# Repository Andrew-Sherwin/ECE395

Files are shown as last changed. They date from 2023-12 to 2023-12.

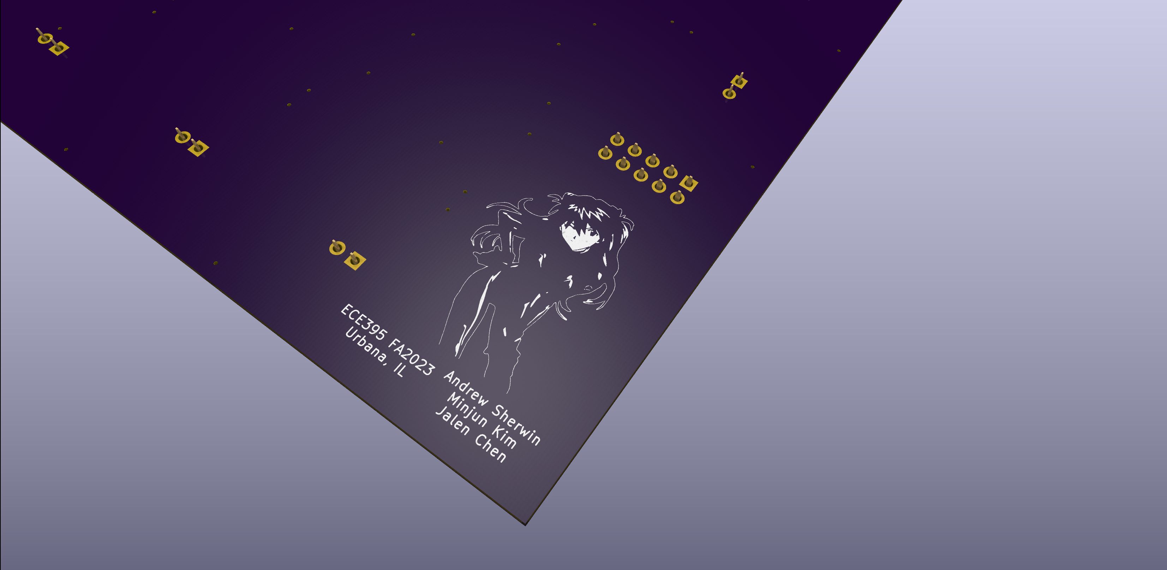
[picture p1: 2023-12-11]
Digital Target System/PCB Art/Asuka Langley/Screen Shot 2023-11-08 at 3.00.52 AM.png

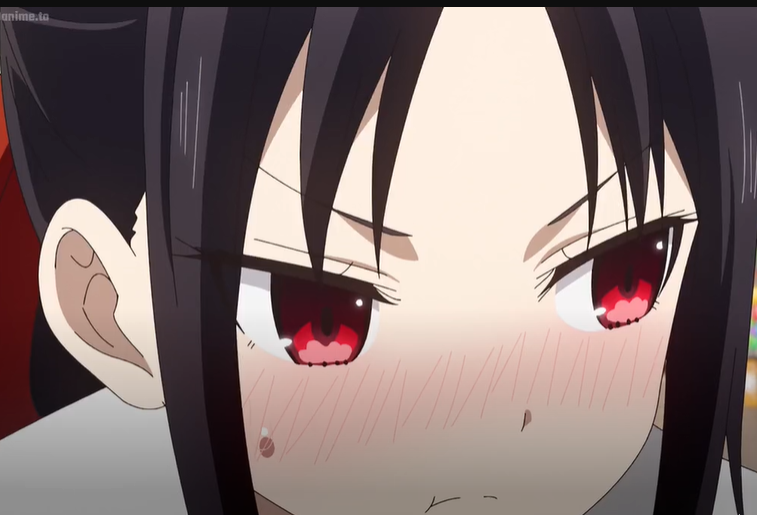
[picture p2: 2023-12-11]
Digital Target System/PCB Art/jalen.png

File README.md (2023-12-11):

# ECE395
Advanced Digital Projects Laboratory
Project: Digital Target System

The Digital Target System folder contains 6 files:
1. Digital Target System Report.pdf
	- This contains the report documenting the design of the product. 
2. DigitalTargetSystem Code (folder)
	- This contains the C code necessary to program the product (if reprogramming or a new revision is needed). 
3. PCB Art (folder)
	- This contains some ART for the silkscreens.
4. PCB with Art (folder)
	- This contains Rev10 PCB KiCad files with Art (unorganized). 
5. Rev8 KiCad Files (folder)
	- This contains Rev8 PCB. A version of the PCB without switches. Power is from the barrel-jack ONLY. 
6. Rev10 KiCad Files (folder)
	- This contains Rev10 PCB. A versino of the PCB wit switches. Power can be from barrel-jack or alternate power source such as a DC Power Supply. 

Updated: December 10, 2023 19:24 CST - Andrew Sherwin

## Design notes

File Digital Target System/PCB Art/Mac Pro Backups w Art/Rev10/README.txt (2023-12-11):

11/06/2023 22:11

- Added switches to toggle which power source to use.

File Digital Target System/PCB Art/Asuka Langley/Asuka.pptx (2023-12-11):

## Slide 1

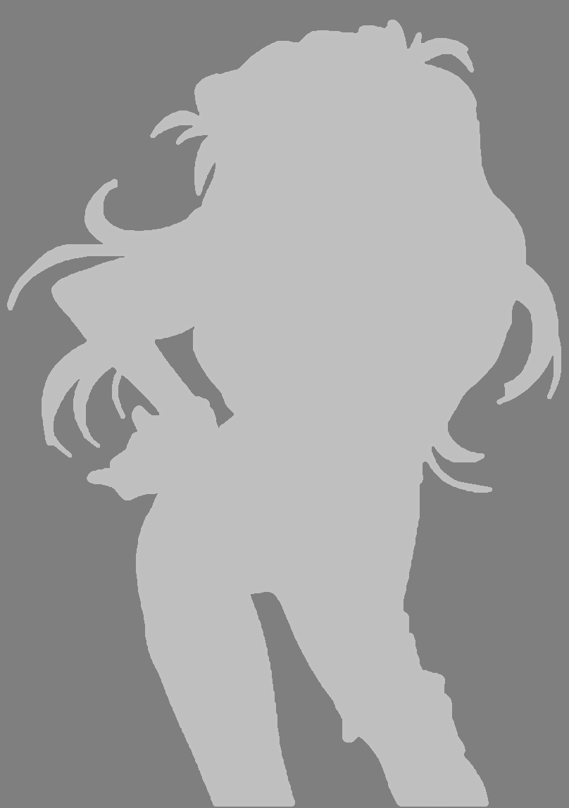
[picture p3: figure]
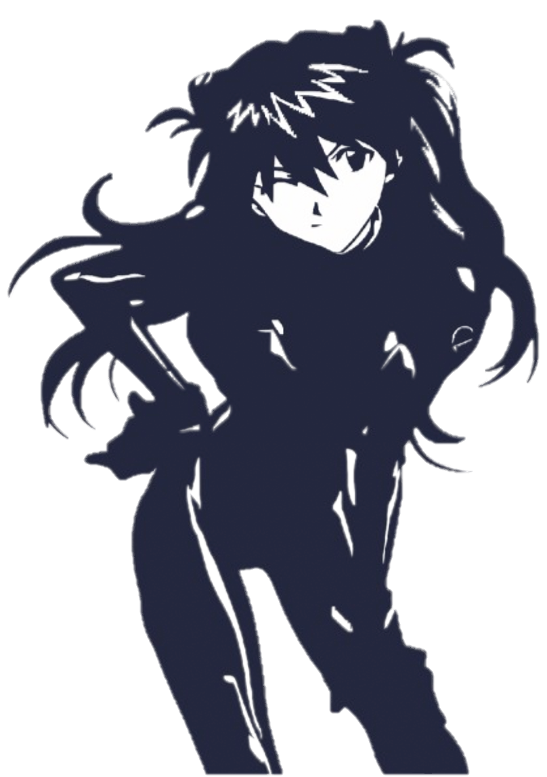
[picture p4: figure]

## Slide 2

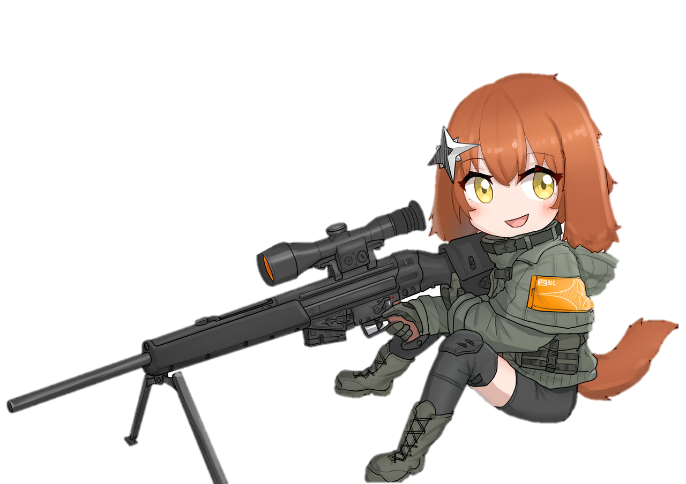
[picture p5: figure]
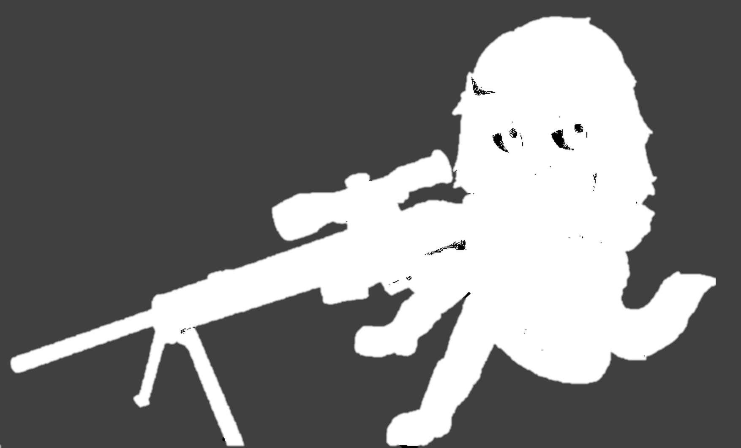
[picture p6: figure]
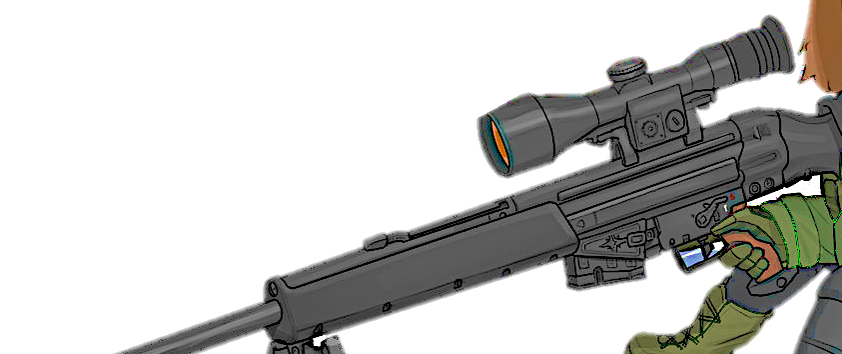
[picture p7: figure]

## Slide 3

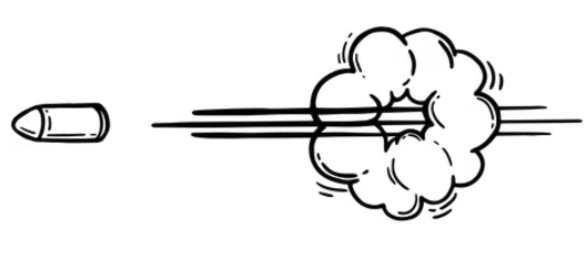
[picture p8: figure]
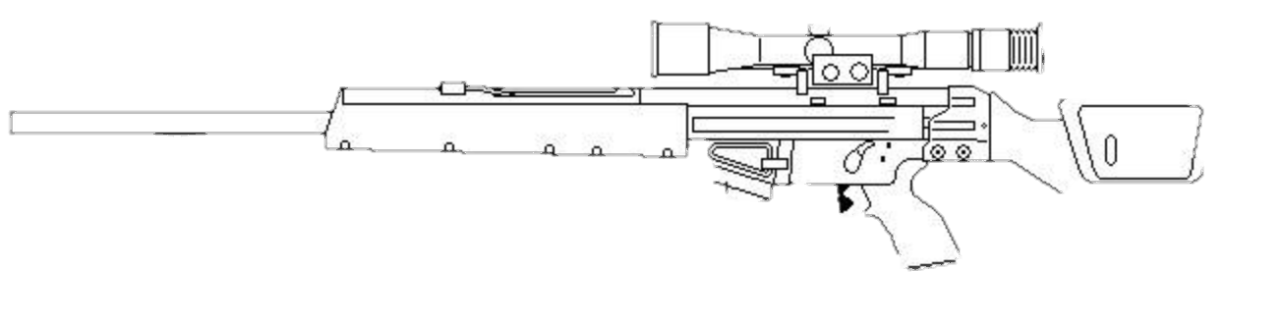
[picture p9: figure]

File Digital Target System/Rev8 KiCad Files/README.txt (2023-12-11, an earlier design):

11/04/2023 16:50

- Fixed power regulator. Matches schematic online now. 
- Rerouted wiring in PCB Editor
- No errors and warnings in schematic mode 
- No errors and 2 warnings about regulator footprint in PCB Editor mode

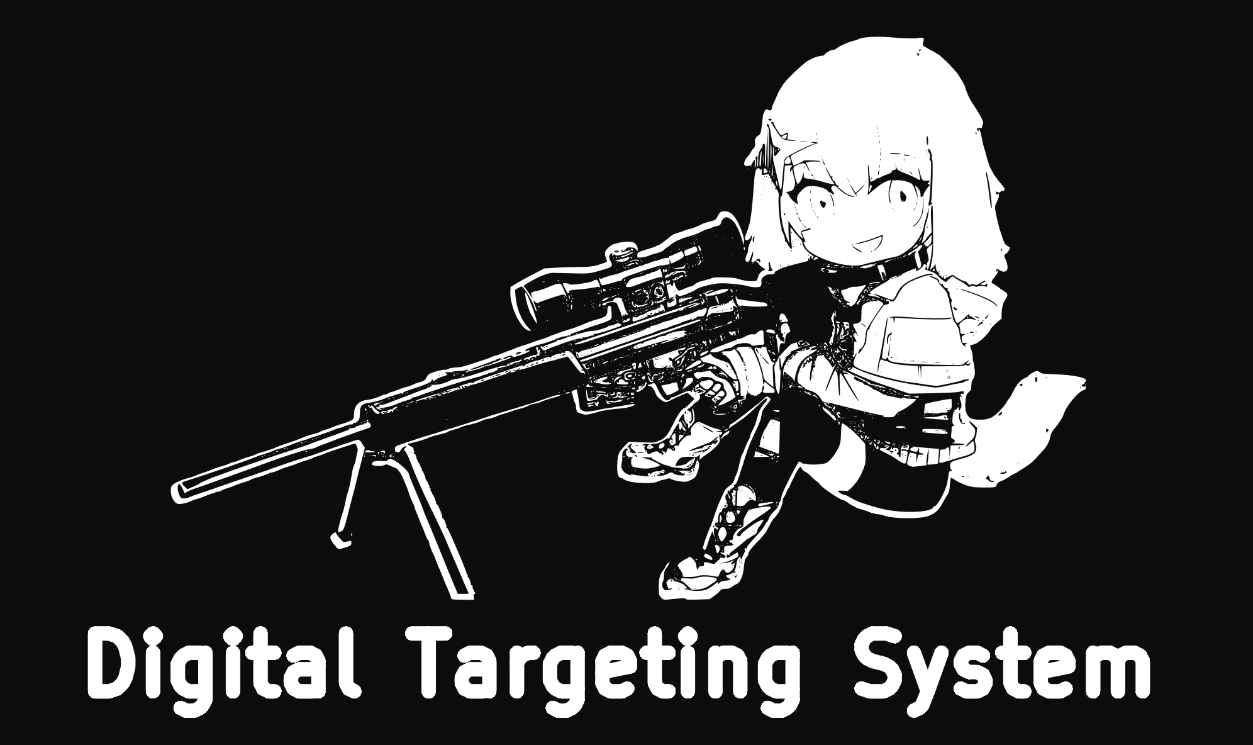
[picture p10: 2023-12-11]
Digital Target System/PCB Art/PSG Anime Girl/Screen Shot 2023-11-18 at 3.14.25 AM.png

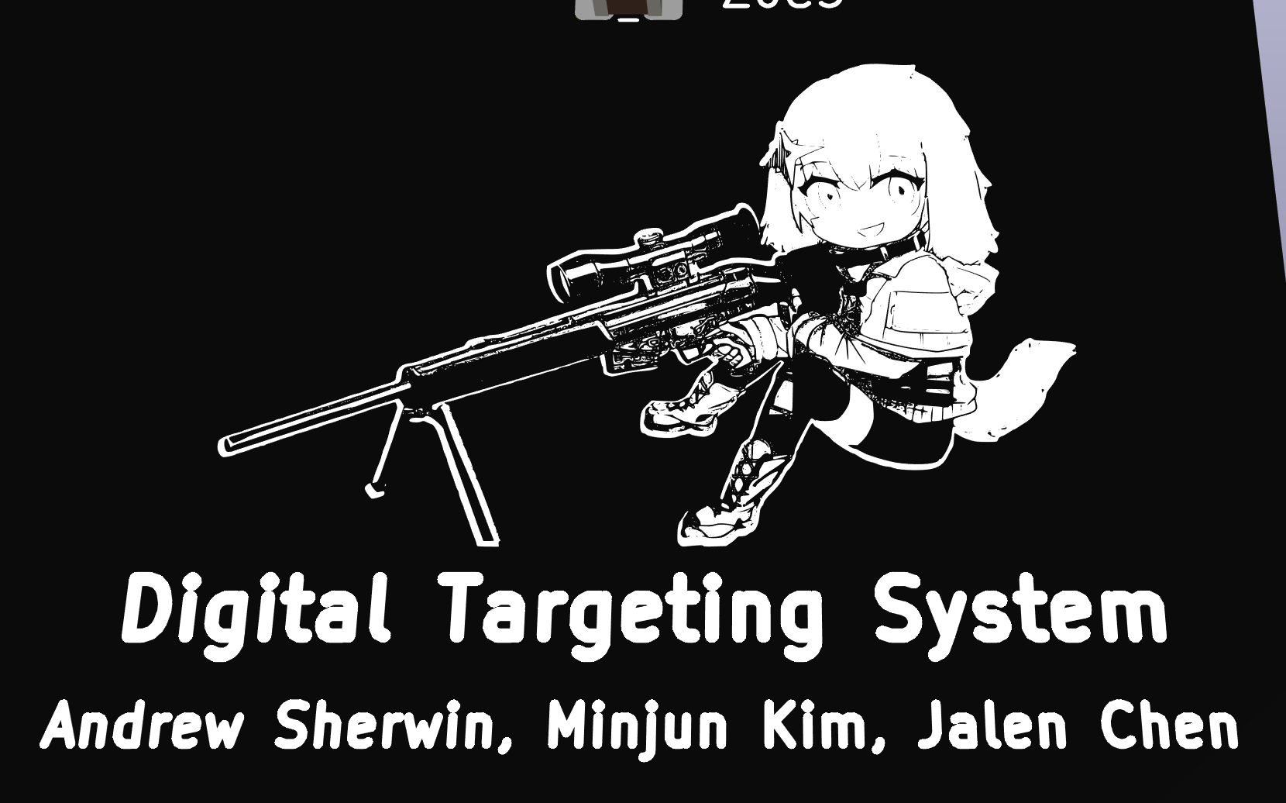
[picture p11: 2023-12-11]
Digital Target System/PCB Art/PSG Anime Girl/Screen Shot 2023-11-18 at 3.06.46 AM.png

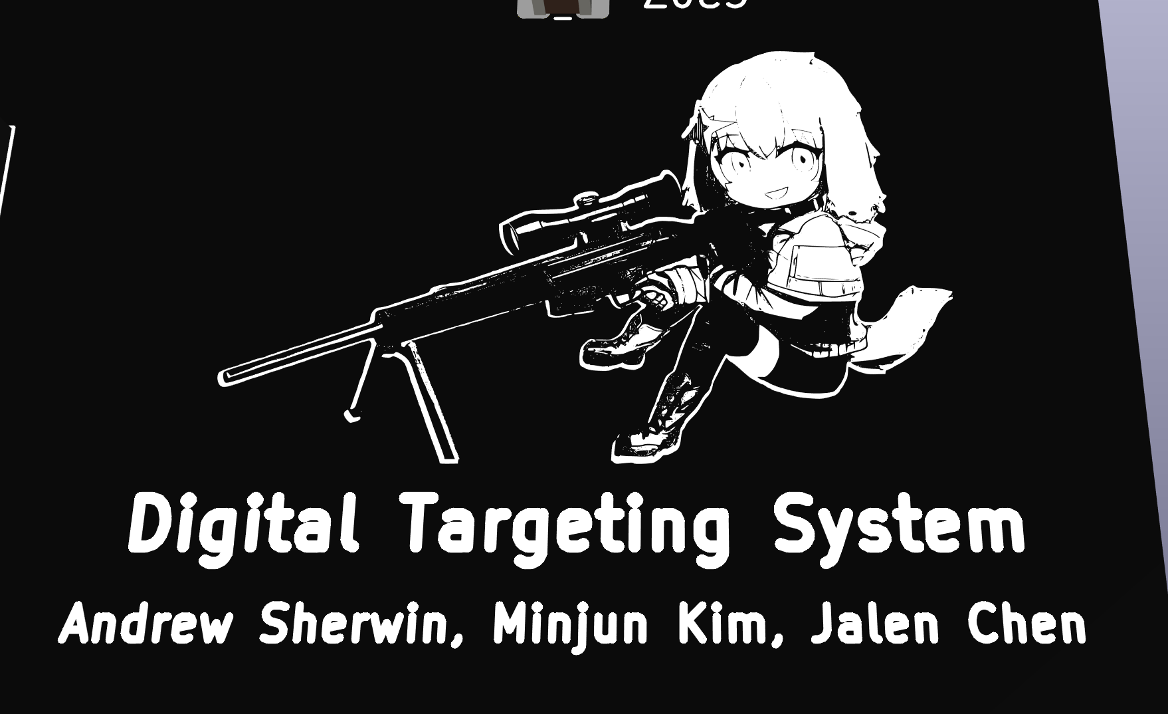
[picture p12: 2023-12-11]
Digital Target System/PCB Art/PSG Anime Girl/Screen Shot 2023-11-18 at 3.08.06 AM.png

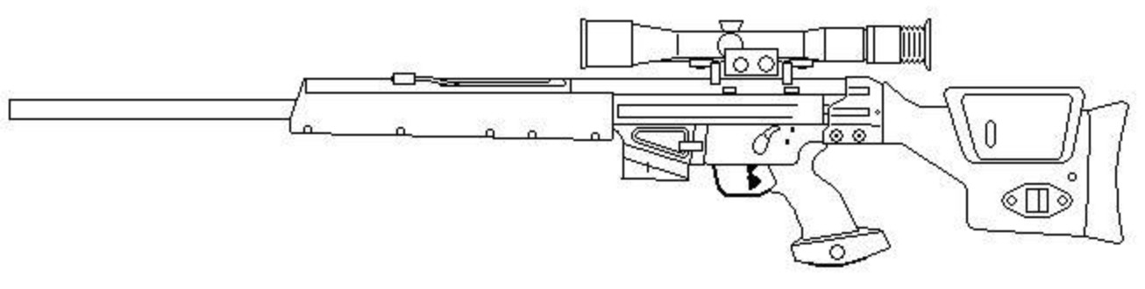
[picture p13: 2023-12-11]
Digital Target System/PCB Art/PSG Anime Girl/Screen Shot 2023-11-18 at 2.02.19 AM.png

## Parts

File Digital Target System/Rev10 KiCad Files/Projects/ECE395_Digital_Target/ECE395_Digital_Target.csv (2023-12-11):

Source: | /Users/andrewxie/Downloads/Rev10/Projects_zyxie2/ECE395_Digital_Target/ECE395_Digital_Target.kicad_sch
Date: | Monday, November 20, 2023 at 01:54:20 AM
Tool: | Eeschema (6.0.11-0)
Generator: | /Applications/KiCad 6.0/KiCad.app/Contents/SharedSupport/plugins/bom_csv_grouped_by_value_with_fp.py
Component Count: | 140
Ref | Qnty | Value | Cmp name | Footprint | Description | Vendor
10uF1, 10uF2, 10uF3, 10uF4, | 4 | 0.00001 | C | Capacitor_SMD:C_0805_2012Metric_Pad1.18x1.45mm_HandSolder | Unpolarized capacitor
C201, C202, C203, C204, C205, C206, C207, C208, C209, C221, C222, C223, C224, C225, C226, C227, C228, C229, C240, C241, C242, | 21 | 10uF | C | Capacitor_SMD:C_0805_2012Metric_Pad1.18x1.45mm_HandSolder | Unpolarized capacitor
C211, C212, C213, C214, C215, C216, C217, C218, C219, C231, C232, C233, C234, C235, C236, C237, C238, C239, C250, C251, C252, | 21 | 0.1uF | C | Capacitor_SMD:C_0805_2012Metric_Pad1.18x1.45mm_HandSolder | Unpolarized capacitor
C300, | 1 | C | C | Capacitor_SMD:C_0805_2012Metric_Pad1.18x1.45mm_HandSolder | Unpolarized capacitor
CR1, CR2, | 2 | LD1117SC-R | LD1117SC-R | Digital_Target:LD1117SC_R
D1, D2, D3, D4, D5, D6, D7, D8, D9, | 9 | LED | LED | LED_SMD:LED_0805_2012Metric_Pad1.15x1.40mm_HandSolder | Light emitting diode
J0, | 1 | PJ-202AH | PJ-202AH | Digital_Target:PJ_202AH
J1, J2, J3, J4, J5, J6, J7, J8, J9, | 9 | Conn_01x02 | Conn_01x02 | Connector_PinSocket_2.54mm:PinSocket_1x02_P2.54mm_Horizontal | Generic connector, single row, 01x02, script generated (kicad-library-utils/schlib/autogen/connector/)
J112, J133, J166, J999, | 4 | Conn_01x01 | Conn_01x01 | Connector_PinSocket_2.54mm:PinSocket_1x01_P2.54mm_Horizontal | Generic connector, single row, 01x01, script generated (kicad-library-utils/schlib/autogen/connector/)
NOT1, NOT2, | 2 | SN74LS04DR | SN74LS04DR | Digital_Target:SN74LS04DR
OP1, OP2, OP3, OP4, OP5, OP6, OP7, OP8, OP9, | 9 | TLC271CDR | TLC271CDR | Digital_Target:TLC271CDR
R1, R2, R3, R4, R5, R6, R7, R8, R9, | 9 | 380 | R | Resistor_SMD:R_0805_2012Metric_Pad1.20x1.40mm_HandSolder | Resistor
R11, R12, R13, R14, R15, R16, R17, R18, R19, | 9 | 20000 | R | Resistor_SMD:R_0805_2012Metric_Pad1.20x1.40mm_HandSolder | Resistor
R21, R22, R23, R24, R25, R26, R27, R28, R29, | 9 | 100000 | R | Resistor_SMD:R_0805_2012Metric_Pad1.20x1.40mm_HandSolder | Resistor
R31, R32, R33, R34, R35, R36, R37, R38, R39, | 9 | 50 | R | Resistor_SMD:R_0805_2012Metric_Pad1.20x1.40mm_HandSolder | Resistor
R41, R42, R43, R44, R45, R46, R47, R48, R49, | 9 | 330 | R | Resistor_SMD:R_0805_2012Metric_Pad1.20x1.40mm_HandSolder | Resistor
R100, R101, | 2 | 120 | R | Resistor_SMD:R_0805_2012Metric_Pad1.20x1.40mm_HandSolder | Resistor
R102, R103, | 2 | ? | R | Resistor_SMD:R_0805_2012Metric_Pad1.20x1.40mm_HandSolder | Resistor
S1, | 1 | Conn_02x05_Odd_Even | Conn_02x05_Odd_Even | Connector_PinSocket_2.54mm:PinSocket_2x05_P2.54mm_Vertical | Generic connector, double row, 02x05, odd/even pin numbering scheme (row 1 odd numbers, row 2 even numbers), script generated (kicad-library-utils/schlib/autogen/connector/)
S2, | 1 | Conn_01x06 | Conn_01x06 | Connector_PinSocket_2.54mm:PinSocket_1x06_P2.54mm_Horizontal | Generic connector, single row, 01x06, script generated (kicad-library-utils/schlib/autogen/connector/)
S63, S65, S350, S550, | 4 | 100SP1T1B4M2QE | 100SP1T1B4M2QE | Digital_Target:SW_100SP1T1B4M2QE
SW1, | 1 | SW_Push | SW_Push | Button_Switch_THT:SW_PUSH_6mm_H4.3mm | Push button switch, generic, two pins
U1, | 1 | STM32L031K6Tx | STM32L031K6Tx | Package_QFP:LQFP-32_7x7mm_P0.8mm | ARM Cortex-M0+ MCU, 32KB flash, 8KB RAM, 32MHz, 1.65-3.6V, 25 GPIO, LQFP-32

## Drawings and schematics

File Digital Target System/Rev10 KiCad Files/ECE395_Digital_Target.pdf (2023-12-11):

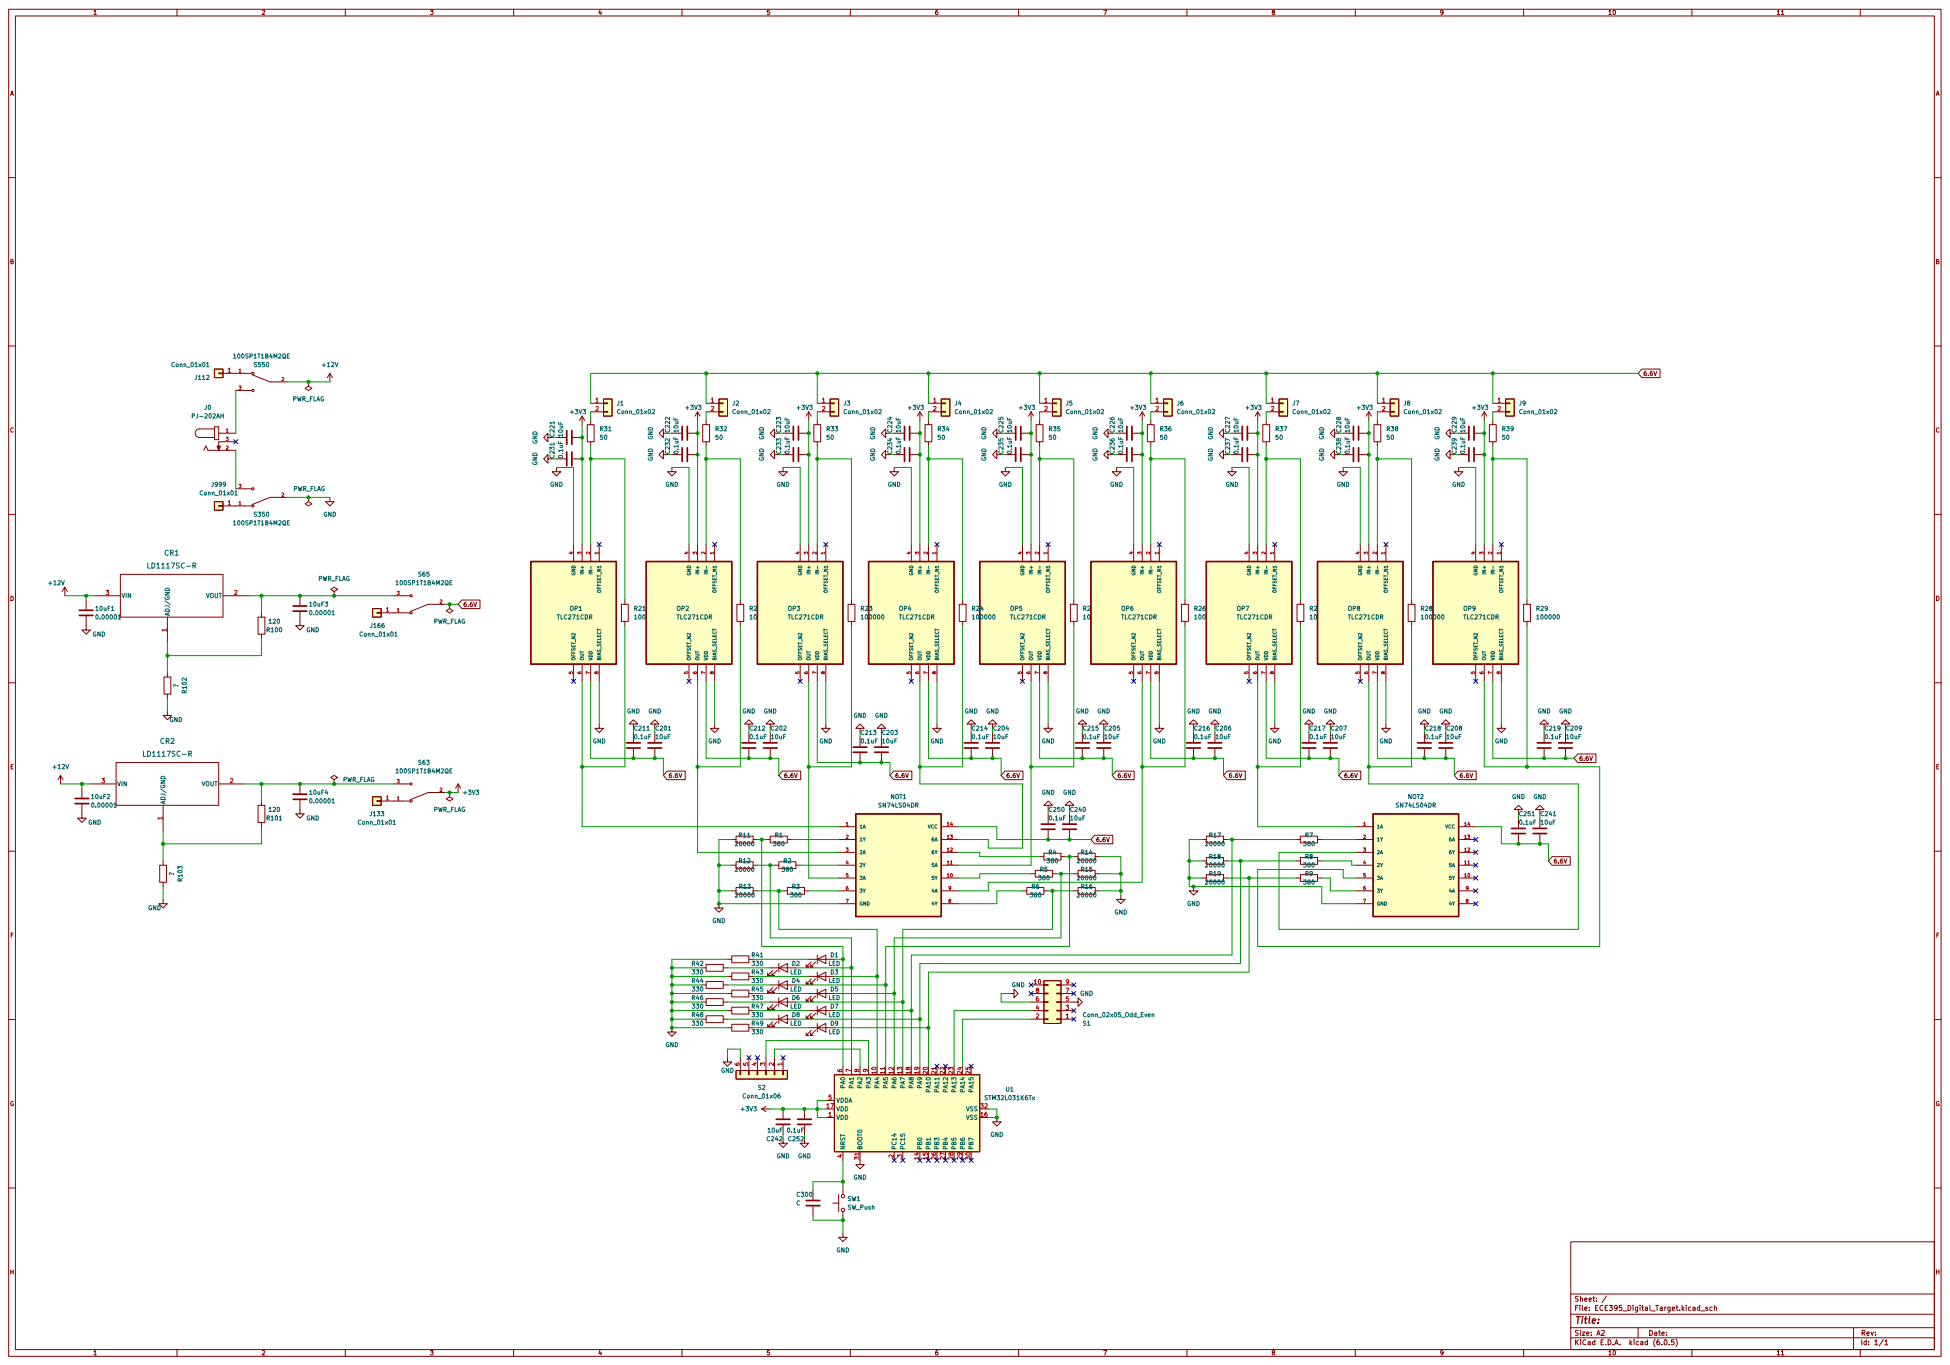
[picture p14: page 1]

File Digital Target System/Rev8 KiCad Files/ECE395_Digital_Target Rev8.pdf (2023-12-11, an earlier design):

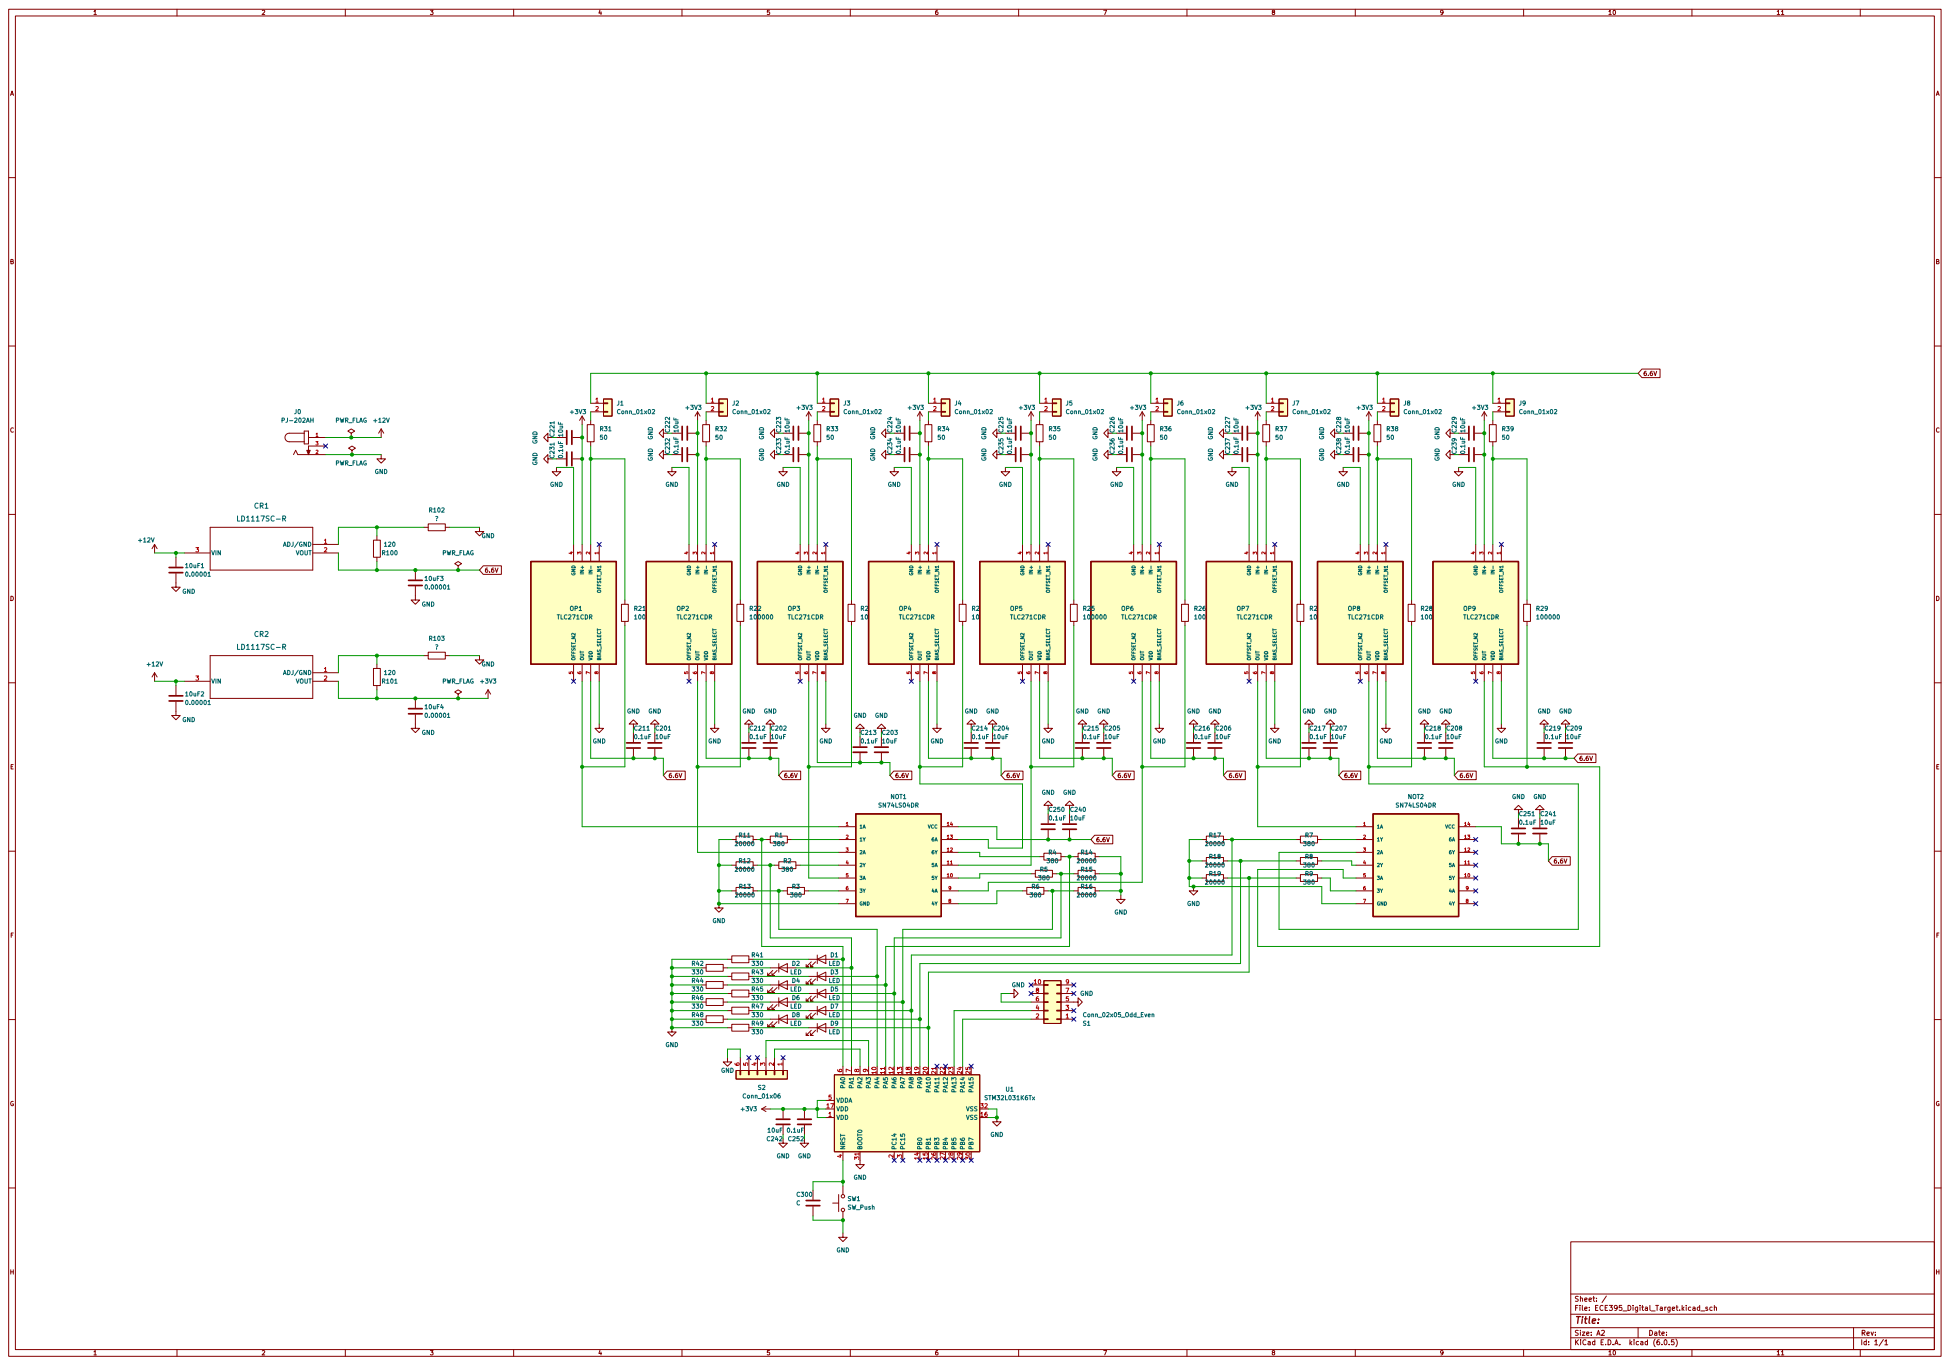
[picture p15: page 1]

GND GND

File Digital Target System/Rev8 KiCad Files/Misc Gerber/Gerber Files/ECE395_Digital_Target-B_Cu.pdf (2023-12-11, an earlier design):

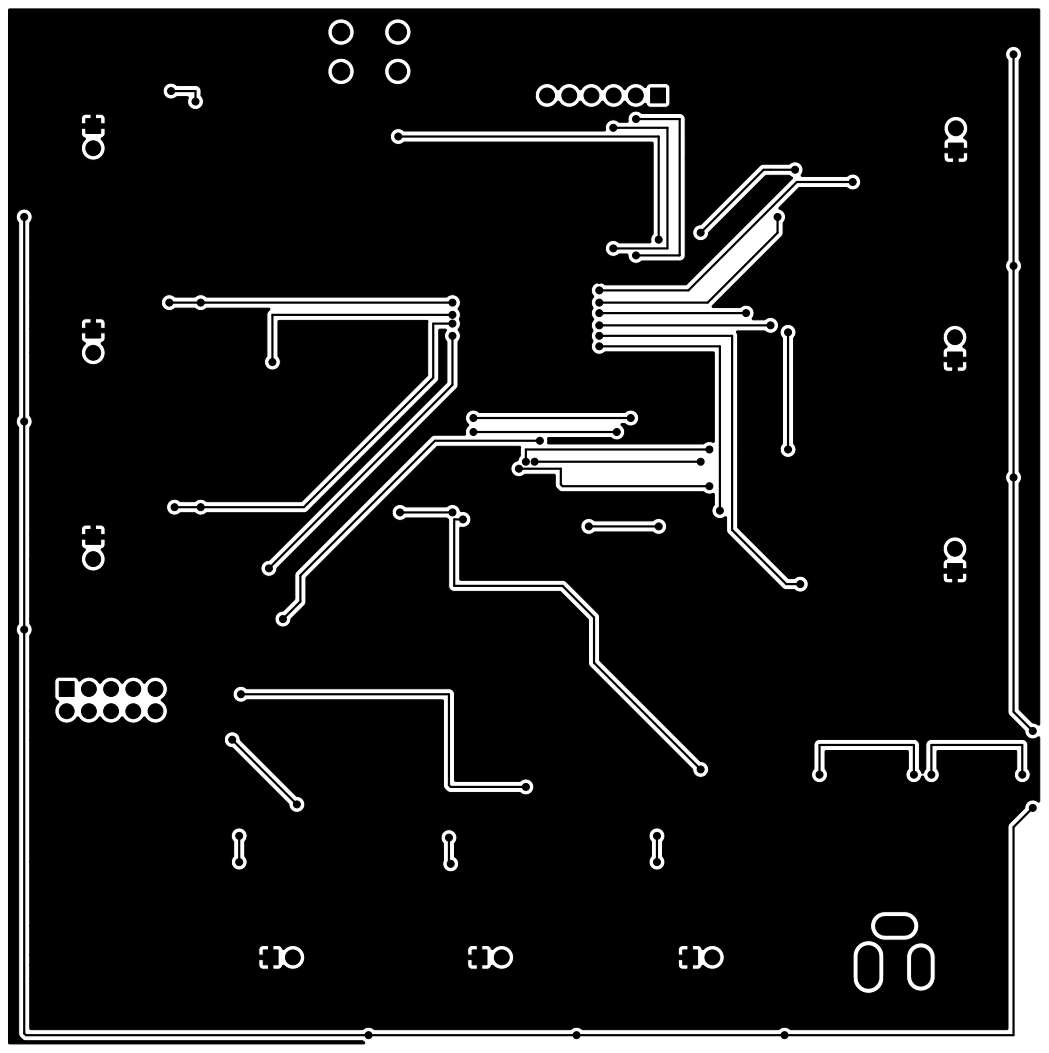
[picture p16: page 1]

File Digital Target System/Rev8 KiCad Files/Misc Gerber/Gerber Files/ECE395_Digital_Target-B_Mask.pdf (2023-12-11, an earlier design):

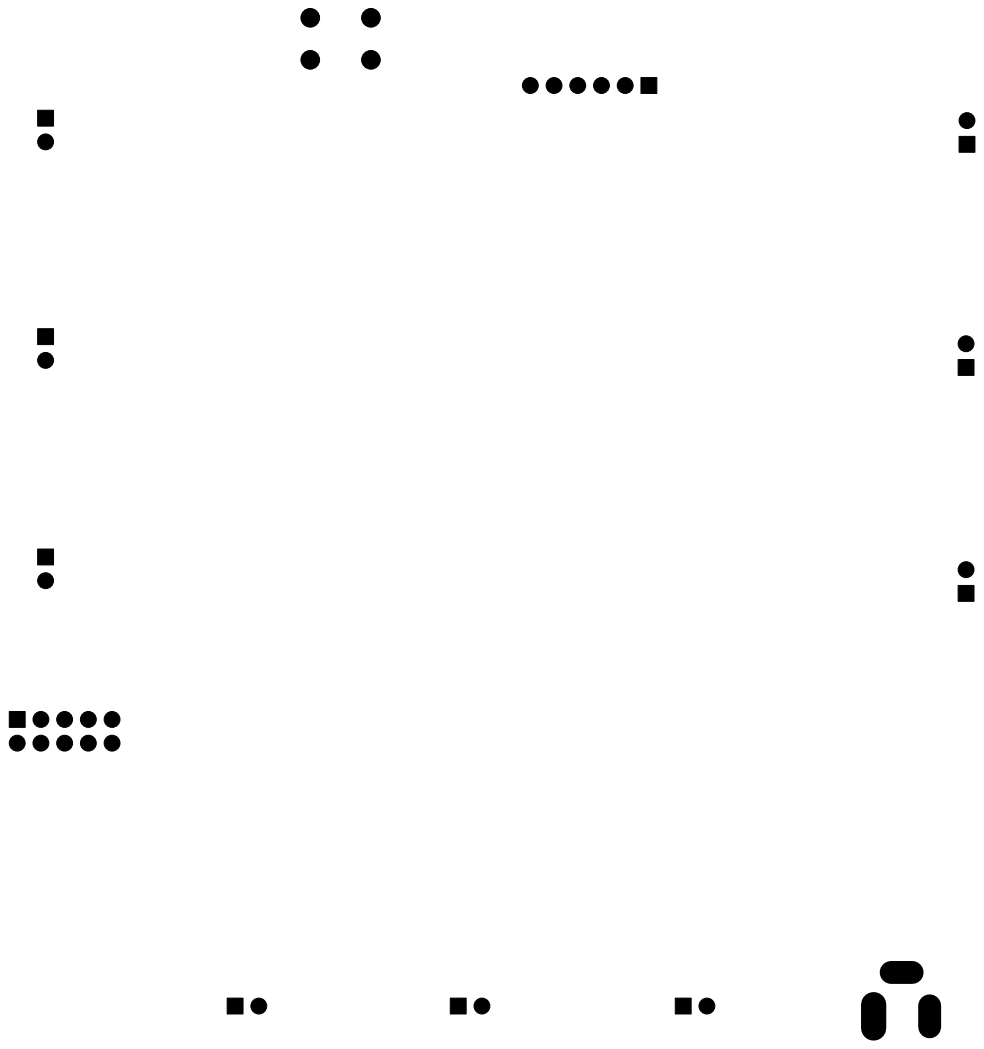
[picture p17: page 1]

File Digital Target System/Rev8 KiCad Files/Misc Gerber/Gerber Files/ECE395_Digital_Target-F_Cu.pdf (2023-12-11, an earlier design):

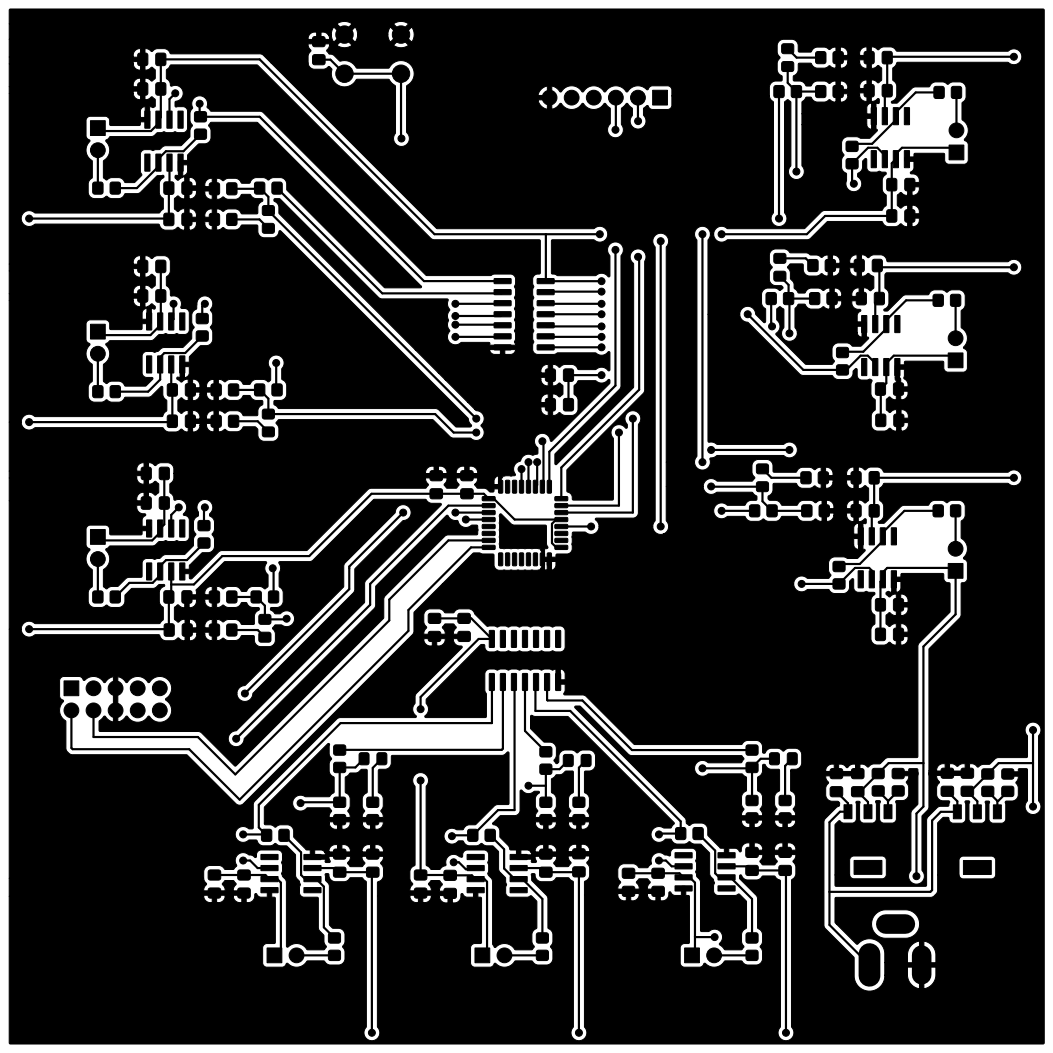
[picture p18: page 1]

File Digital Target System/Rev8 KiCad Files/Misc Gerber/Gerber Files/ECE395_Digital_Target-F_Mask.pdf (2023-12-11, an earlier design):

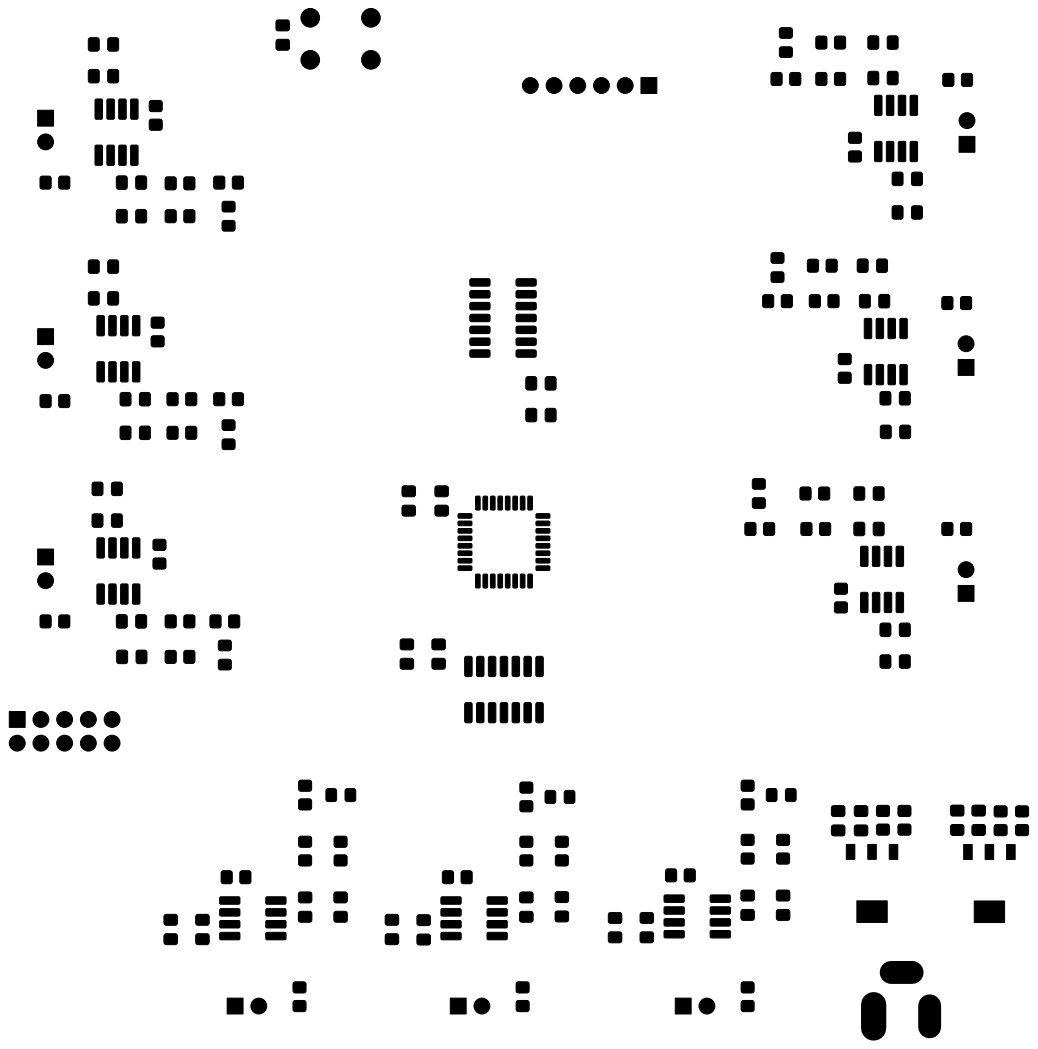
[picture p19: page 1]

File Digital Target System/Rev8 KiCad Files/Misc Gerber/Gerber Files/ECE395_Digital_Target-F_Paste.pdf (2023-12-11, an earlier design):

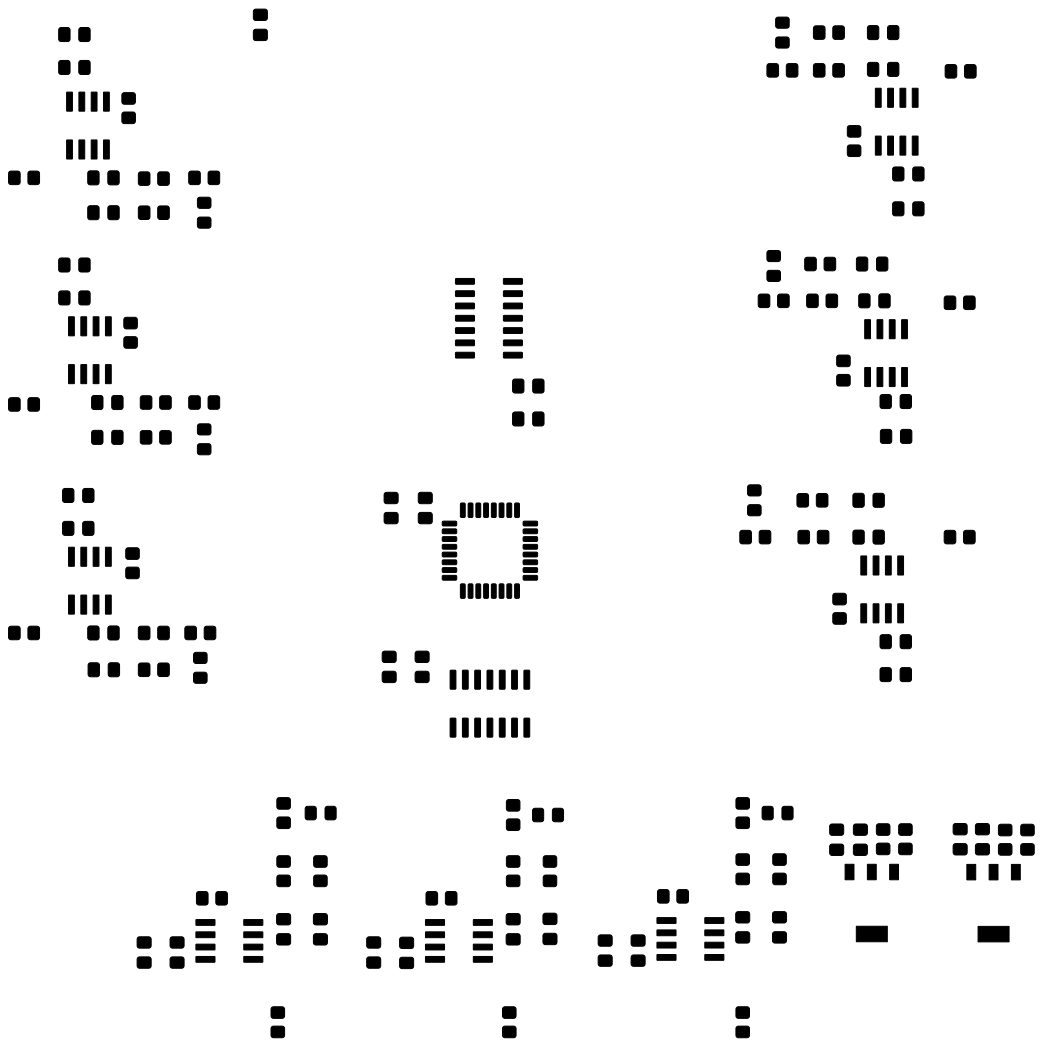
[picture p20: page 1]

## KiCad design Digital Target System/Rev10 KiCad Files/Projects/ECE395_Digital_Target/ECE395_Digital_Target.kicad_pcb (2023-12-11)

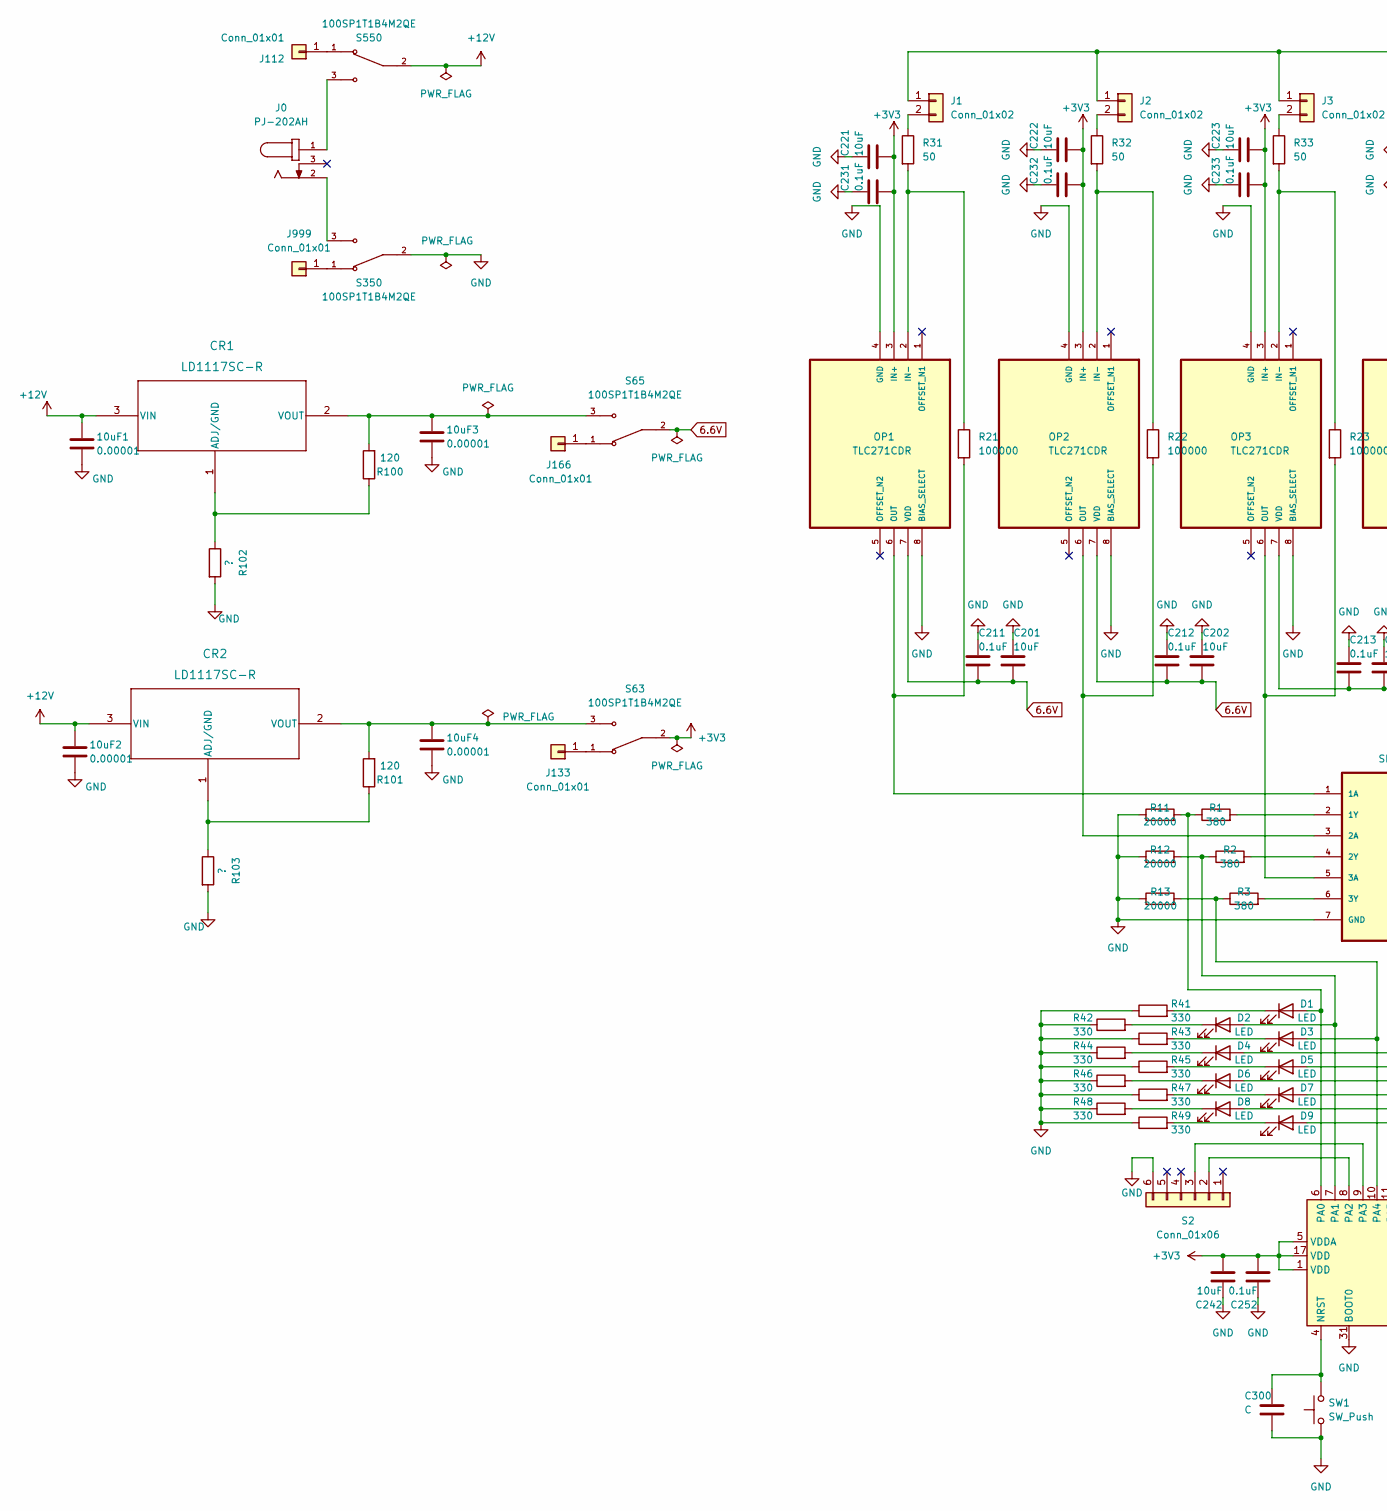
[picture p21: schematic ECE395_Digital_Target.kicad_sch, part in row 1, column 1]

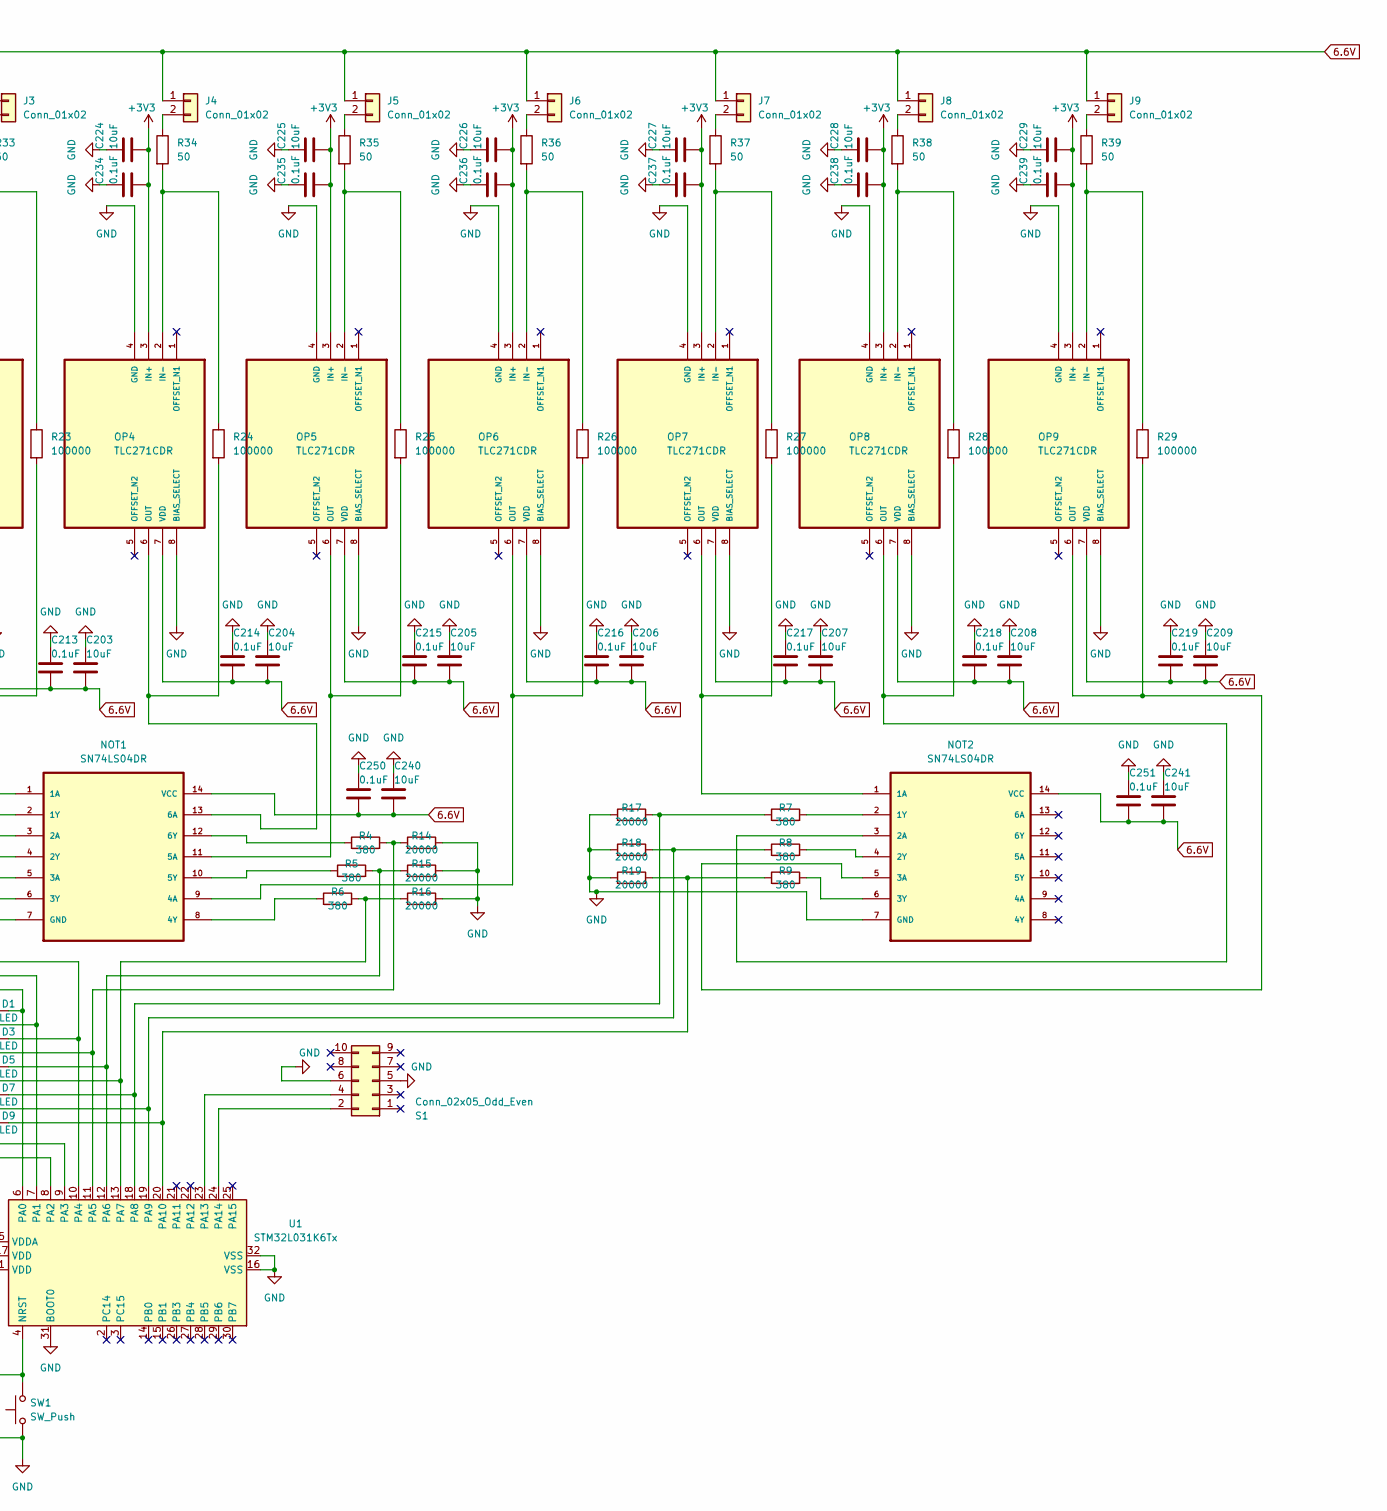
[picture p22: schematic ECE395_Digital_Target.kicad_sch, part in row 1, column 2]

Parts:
10uF1, 10uF2, 10uF3, 10uF4: 0.00001; C_0805_2012Metric_Pad1.18x1.45mm_HandSolder
C201, C202, C203, C204, C205, C206, C207, C208, C209, C221, C222, C223, C224, C225, C226, C227, C228, C229, C240, C241, C242: 10uF; C_0805_2012Metric_Pad1.18x1.45mm_HandSolder
C211, C212, C213, C214, C215, C216, C217, C218, C219, C231, C232, C233, C234, C235, C236, C237, C238, C239, C250, C251, C252: 0.1uF; C_0805_2012Metric_Pad1.18x1.45mm_HandSolder
C300: C; C_0805_2012Metric_Pad1.18x1.45mm_HandSolder
CR1, CR2: LD1117SC-R; LD1117SC_R
D1, D2, D3, D4, D5, D6, D7, D8, D9: LED; LED_0805_2012Metric_Pad1.15x1.40mm_HandSolder
J0: PJ-202AH; PJ_202AH; PART_REV 1.02
J1, J2, J3, J4, J5, J6, J7, J8, J9: Conn_01x02; PinSocket_1x02_P2.54mm_Horizontal
J112, J133, J166, J999: Conn_01x01; PinSocket_1x01_P2.54mm_Horizontal
NOT1, NOT2: SN74LS04DR
OP1, OP2, OP3, OP4, OP5, OP6, OP7, OP8, OP9: TLC271CDR
R1, R2, R3, R4, R5, R6, R7, R8, R9: 380; R_0805_2012Metric_Pad1.20x1.40mm_HandSolder
R11, R12, R13, R14, R15, R16, R17, R18, R19: 20000; R_0805_2012Metric_Pad1.20x1.40mm_HandSolder
R21, R22, R23, R24, R25, R26, R27, R28, R29: 100000; R_0805_2012Metric_Pad1.20x1.40mm_HandSolder
R31, R32, R33, R34, R35, R36, R37, R38, R39: 50; R_0805_2012Metric_Pad1.20x1.40mm_HandSolder
R41, R42, R43, R44, R45, R46, R47, R48, R49: 330; R_0805_2012Metric_Pad1.20x1.40mm_HandSolder
R100, R101: 120; R_0805_2012Metric_Pad1.20x1.40mm_HandSolder
R102, R103: ?; R_0805_2012Metric_Pad1.20x1.40mm_HandSolder
S1: Conn_02x05_Odd_Even; PinSocket_2x05_P2.54mm_Vertical
S2: Conn_01x06; PinSocket_1x06_P2.54mm_Horizontal
S63, S65, S350, S550: 100SP1T1B4M2QE; SW_100SP1T1B4M2QE; PARTREV E
SW1: SW_Push; SW_PUSH_6mm_H4.3mm
U1: STM32L031K6Tx; LQFP-32_7x7mm_P0.8mm

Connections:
6.6V: C201.2, C202.2, C203.2, C204.2, C205.2, C206.2, C207.2, C208.2, C209.2, C211.2, C212.2, C213.2, C214.2, C215.2, C216.2, C217.2, C218.2, C219.2, C240.2, C241.2, C250.2, C251.2, J1.1, J2.1, J3.1, J4.1, J5.1, J6.1, J7.1, J8.1, J9.1, NOT1.14 (VCC), NOT2.14 (VCC), OP1.7 (VDD), OP2.7 (VDD), OP3.7 (VDD), OP4.7 (VDD), OP5.7 (VDD), OP6.7 (VDD), OP7.7 (VDD), OP8.7 (VDD), OP9.7 (VDD), S65.2
+3V3: C221.2, C222.2, C223.2, C224.2, C225.2, C226.2, C227.2, C228.2, C229.2, C231.2, C232.2, C233.2, C234.2, C235.2, C236.2, C237.2, C238.2, C239.2, C242.2, C252.2, OP1.3 (IN+), OP2.3 (IN+), OP3.3 (IN+), OP4.3 (IN+), OP5.3 (IN+), OP6.3 (IN+), OP7.3 (IN+), OP8.3 (IN+), OP9.3 (IN+), S63.2, U1.1 (VDD), U1.5 (VDDA), U1.17 (VDD)
+12V: 10uF1.1, 10uF2.1, CR1.3 (VIN), CR2.3 (VIN), S550.2
GND: 10uF1.2, 10uF2.2, 10uF3.2, 10uF4.2, C201.1, C202.1, C203.1, C204.1, C205.1, C206.1, C207.1, C208.1, C209.1, C211.1, C212.1, C213.1, C214.1, C215.1, C216.1, C217.1, C218.1, C219.1, C221.1, C222.1, C223.1, C224.1, C225.1, C226.1, C227.1, C228.1, C229.1, C231.1, C232.1, C233.1, C234.1, C235.1, C236.1, C237.1, C238.1, C239.1, C240.1, C241.1, C242.1, C250.1, C251.1, C252.1, C300.2, NOT1.7 (GND), NOT2.7 (GND), OP1.4 (GND), OP1.8 (BIAS_SELECT), OP2.4 (GND), OP2.8 (BIAS_SELECT), OP3.4 (GND), OP3.8 (BIAS_SELECT), OP4.4 (GND), OP4.8 (BIAS_SELECT), OP5.4 (GND), OP5.8 (BIAS_SELECT), OP6.4 (GND), OP6.8 (BIAS_SELECT), OP7.4 (GND), OP7.8 (BIAS_SELECT), OP8.4 (GND), OP8.8 (BIAS_SELECT), OP9.4 (GND), OP9.8 (BIAS_SELECT), R11.1, R12.1, R13.1, R14.2, R15.2, R16.2, R17.1, R18.1, R19.1, R41.1, R42.1, R43.1, R44.1, R45.1, R46.1, R47.1, R48.1, R49.1, R102.2, R103.2, S1.5, S1.6, S2.6, S350.2, SW1.1, U1.16 (VSS), U1.31 (BOOT0), U1.32 (VSS)
unnamed: 10uF3.1, CR1.2 (VOUT), R100.2, S65.3
unnamed: 10uF4.1, CR2.2 (VOUT), R101.2, S63.3
unnamed: C300.1, SW1.2, U1.4 (NRST)
unnamed: CR1.1 (ADJ/GND), R100.1, R102.1
unnamed: CR2.1 (ADJ/GND), R101.1, R103.1
unnamed: D1.1 (K), R41.2
unnamed: D1.2 (A), R1.1, R11.2, U1.6 (PA0)
unnamed: D2.1 (K), R42.2
unnamed: D2.2 (A), R2.1, R12.2, U1.7 (PA1)
unnamed: D3.1 (K), R43.2
unnamed: D3.2 (A), R3.1, R13.2, U1.10 (PA4)
unnamed: D4.1 (K), R44.2
unnamed: D4.2 (A), R4.2, R14.1, U1.11 (PA5)
unnamed: D5.1 (K), R45.2
unnamed: D5.2 (A), R5.2, R15.1, U1.12 (PA6)
unnamed: D6.1 (K), R46.2
unnamed: D6.2 (A), R6.2, R16.1, U1.13 (PA7)
unnamed: D7.1 (K), R47.2
unnamed: D7.2 (A), R7.1, R17.2, U1.18 (PA8)
unnamed: D8.1 (K), R48.2
unnamed: D8.2 (A), R8.1, R18.2, U1.19 (PA9)
unnamed: D9.1 (K), R49.2
unnamed: D9.2 (A), R9.1, R19.2, U1.20 (PA10)
unnamed: J0.1, S550.3
unnamed: J0.2, S350.3
unnamed: J1.2, R31.1
unnamed: J2.2, R32.1
unnamed: J3.2, R33.1
unnamed: J4.2, R34.1
unnamed: J5.2, R35.1
unnamed: J6.2, R36.1
unnamed: J7.2, R37.1
unnamed: J8.2, R38.1
unnamed: J9.2, R39.1
unnamed: J112.1, S550.1
unnamed: J133.1, S63.1
unnamed: J166.1, S65.1
unnamed: J999.1, S350.1
unnamed: NOT1.1 (1A), OP1.6 (OUT), R21.2
unnamed: NOT1.2 (1Y), R1.2
unnamed: NOT1.3 (2A), OP2.6 (OUT), R22.2
unnamed: NOT1.4 (2Y), R2.2
unnamed: NOT1.5 (3A), OP3.6 (OUT), R23.2
unnamed: NOT1.6 (3Y), R3.2
unnamed: NOT1.8 (4Y), R6.1
unnamed: NOT1.9 (4A), OP6.6 (OUT), R26.2
unnamed: NOT1.10 (5Y), R5.1
unnamed: NOT1.11 (5A), OP5.6 (OUT), R25.2
unnamed: NOT1.12 (6Y), R4.1
unnamed: NOT1.13 (6A), OP4.6 (OUT), R24.2
unnamed: NOT2.1 (1A), OP7.6 (OUT), R27.2
unnamed: NOT2.2 (1Y), R7.2
unnamed: NOT2.3 (2A), OP8.6 (OUT), R28.2
unnamed: NOT2.4 (2Y), R8.2
unnamed: NOT2.5 (3A), OP9.6 (OUT), R29.2
unnamed: NOT2.6 (3Y), R9.2
unnamed: OP1.2 (IN-), R21.1, R31.2
unnamed: OP2.2 (IN-), R22.1, R32.2
unnamed: OP3.2 (IN-), R23.1, R33.2
unnamed: OP4.2 (IN-), R24.1, R34.2
unnamed: OP5.2 (IN-), R25.1, R35.2
unnamed: OP6.2 (IN-), R26.1, R36.2
unnamed: OP7.2 (IN-), R27.1, R37.2
unnamed: OP8.2 (IN-), R28.1, R38.2
unnamed: OP9.2 (IN-), R29.1, R39.2
unnamed: S1.2, U1.24 (PA14)
unnamed: S1.4, U1.23 (PA13)
unnamed: S2.2, U1.8 (PA2)
unnamed: S2.3, U1.9 (PA3)

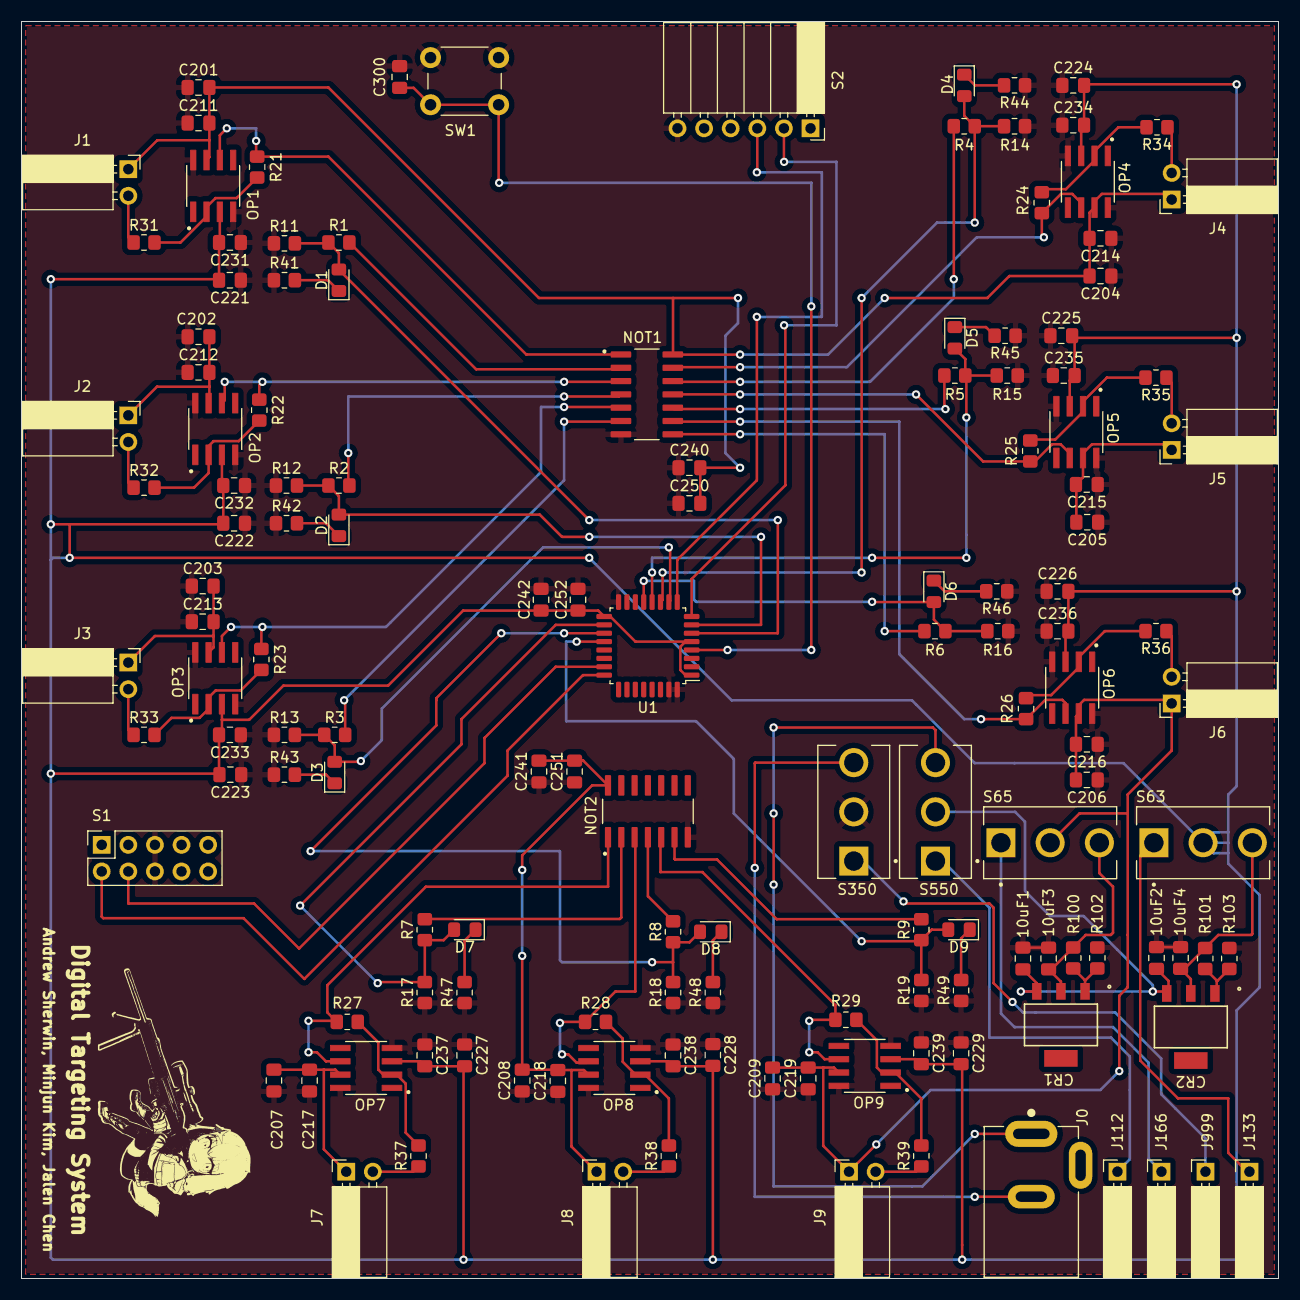
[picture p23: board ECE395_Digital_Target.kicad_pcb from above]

Board: 2 copper layers, 120.0 x 120.0 mm, 140 parts (0 on the bottom side), 73 nets.

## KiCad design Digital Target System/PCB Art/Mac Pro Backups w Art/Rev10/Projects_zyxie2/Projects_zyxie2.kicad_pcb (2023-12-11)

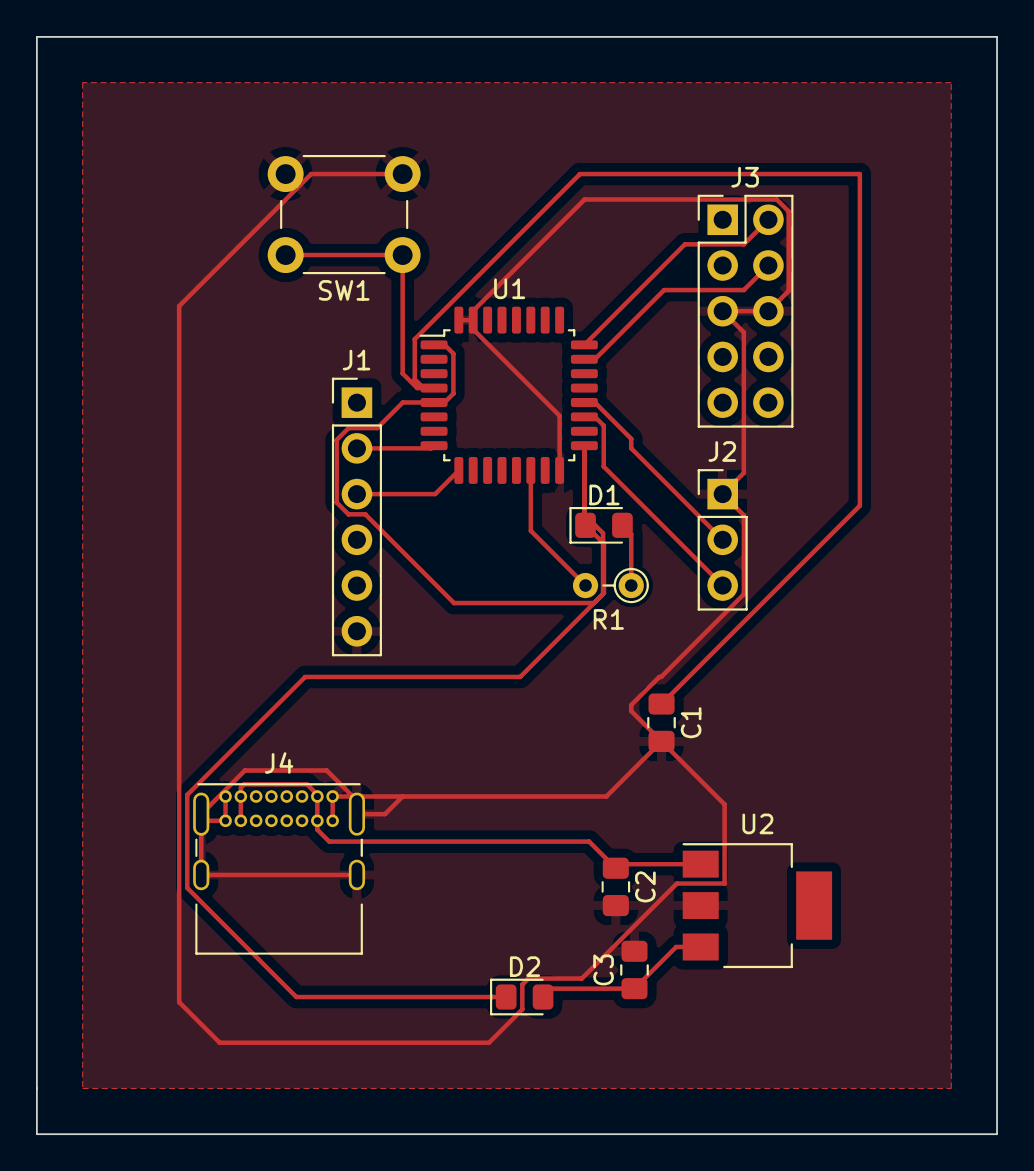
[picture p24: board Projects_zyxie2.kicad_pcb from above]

Board: 2 copper layers, 53.3 x 61.0 mm, 13 parts (0 on the bottom side), 13 nets.

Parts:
C1, C2, C3: 0.000001; C_0805_2012Metric_Pad1.18x1.45mm_HandSolder
D1, D2: LED; LED_0805_2012Metric_Pad1.15x1.40mm_HandSolder
J1: TTL Adapter; PinHeader_1x06_P2.54mm_Vertical
J2: I2C; PinHeader_1x03_P2.54mm_Vertical
J3: ST_Link V2 Programmer; PinHeader_2x05_P2.54mm_Vertical
J4: USB_C_Receptacle_USB2.0; USB_C_Receptacle_GCT_USB4085
R1: 330; R_Axial_DIN0204_L3.6mm_D1.6mm_P2.54mm_Vertical
SW1: SW_Push; SW_PUSH_6mm_H4.3mm
U1: STM32L031K6Tx; LQFP-32_7x7mm_P0.8mm
U2: TC1262-33; SOT-223

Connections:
+3V3: D1.1 (K), D2.1 (K), U1.1 (VDD), U1.5 (VDDA), U1.17 (VDD)
+5V: C2.1, J4.A4 (VBUS), J4.A9 (VBUS), J4.B4 (VBUS), J4.B9 (VBUS), U2.1 (VI)
GND: C1.2, C2.2, C3.2, J1.6, J2.1, J3.5, J3.6, J4.A1 (GND), J4.A12 (GND), J4.B1 (GND), J4.B12 (GND), J4.S1 (SHIELD), SW1.2, U1.16 (VSS), U1.31 (BOOT0), U1.32 (VSS), U2.2 (GND)
unnamed: D1.2 (A), R1.1
unnamed: C3.1, D2.2 (A), U2.3 (VO)
unnamed: J1.2, U1.8 (PA2)
unnamed: J1.3, U1.9 (PA3)
unnamed: J2.2, U1.20 (PA10)
unnamed: J2.3, U1.19 (PA9)
unnamed: J3.2, U1.24 (PA14)
unnamed: J3.4, U1.23 (PA13)
unnamed: C1.1, SW1.1, U1.4 (NRST)
unnamed: R1.2, U1.14 (PB0)

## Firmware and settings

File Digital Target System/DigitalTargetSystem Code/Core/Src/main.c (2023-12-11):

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
/* Includes ------------------------------------------------------------------*/
#include "main.h"

/* USER CODE BEGIN Includes */

#include <math.h>
/* USER CODE END Includes */

UART_HandleTypeDef hlpuart1;

void SystemClock_Config(void);
static void MX_GPIO_Init(void);
static void MX_LPUART1_UART_Init(void);
/**
  * @brief  The application entry point.
  * @retval int
  */
int main(void)
{
  /* MCU Configuration--------------------------------------------------------*/

  /* Reset of all peripherals, Initializes the Flash interface and the Systick. */
  HAL_Init();

  /* Configure the system clock */
  SystemClock_Config();

  /* Initialize all configured peripherals */
  MX_GPIO_Init();
  MX_LPUART1_UART_Init();
  /* USER CODE BEGIN 2 */
//  HAL_UART_Transmit(&huart1,msg1,sizeof(msg1),1000);
//  HAL_UART_Transmit(&huart1,msg2,sizeof(msg2),1000);
//  BSP_ENV_SENSOR_Init(0, ENV_FORCE);
//  BSP_ENV_SENSOR_Enable(0, ENV_FORCE);
//  HAL_UART_Transmit(&huart1,msg3,sizeof(msg3),1000);
  /* USER CODE END 2 */

  /* Infinite loop */
  /* USER CODE BEGIN WHILE */
  while (1)
  {
    /* USER CODE END WHILE */

    /* USER CODE BEGIN 3 */

//	  BSP_ENV_SENSOR_GetValue(0, ENV_FORCE, &force_value);
//	  int forceInt1 = force_value;
//	  float forceFrac = force_value - tmpInt1;
//	  int forceInt2 = trunc(tmpFrac * 100);
//	  snprintf(str_tmp,100," FORCE = %d.%02d\n", forceInt1, forceInt2);
//	  HAL_UART_Transmit(&huart1,( uint8_t *)str_tmp,sizeof(str_tmp),500);

	  if (HAL_GPIO_ReadPin(GPIOA, GPIO_PIN_0) != 0){

    /* USER CODE END WHILE */
		uint8_t Test[] = "Hit 3!!!\r\n"; //Data to send
		HAL_UART_Transmit(&hlpuart1,Test,sizeof(Test),10);// Sending in normal mode
		HAL_Delay(500);

    /* USER CODE BEGIN 3 */
	  }

	  if (HAL_GPIO_ReadPin(GPIOA, GPIO_PIN_1) != 0){

    /* USER CODE END WHILE */
		uint8_t Test[] = "Hit 2!!!\r\n"; //Data to send
		HAL_UART_Transmit(&hlpuart1,Test,sizeof(Test),10);// Sending in normal mode
		HAL_Delay(500);

    /* USER CODE BEGIN 3 */
	  }

	  if (HAL_GPIO_ReadPin(GPIOA, GPIO_PIN_4) != 0){

    /* USER CODE END WHILE */
		uint8_t Test[] = "Hit 1!!!\r\n"; //Data to send
		HAL_UART_Transmit(&hlpuart1,Test,sizeof(Test),10);// Sending in normal mode
		HAL_Delay(500);

    /* USER CODE BEGIN 3 */
	  }

	  if (HAL_GPIO_ReadPin(GPIOA, GPIO_PIN_5) != 0){

    /* USER CODE END WHILE */
		uint8_t Test[] = "Hit 6!!!\r\n"; //Data to send
		HAL_UART_Transmit(&hlpuart1,Test,sizeof(Test),10);// Sending in normal mode
		HAL_Delay(500);

    /* USER CODE BEGIN 3 */
	  }

	  if (HAL_GPIO_ReadPin(GPIOA, GPIO_PIN_6) != 0){

    /* USER CODE END WHILE */
		uint8_t Test[] = "Hit 9!!!\r\n"; //Data to send
		HAL_UART_Transmit(&hlpuart1,Test,sizeof(Test),10);// Sending in normal mode
		HAL_Delay(500);

    /* USER CODE BEGIN 3 */
	  }

	  if (HAL_GPIO_ReadPin(GPIOA, GPIO_PIN_7) != 0){

    /* USER CODE END WHILE */
		uint8_t Test[] = "Hit 8!!!\r\n"; //Data to send
		HAL_UART_Transmit(&hlpuart1,Test,sizeof(Test),10);// Sending in normal mode
		HAL_Delay(500);

    /* USER CODE BEGIN 3 */
	  }

	  if (HAL_GPIO_ReadPin(GPIOA, GPIO_PIN_8) != 0){

    /* USER CODE END WHILE */
		uint8_t Test[] = "Hit 4!!!\r\n"; //Data to send
		HAL_UART_Transmit(&hlpuart1,Test,sizeof(Test),10);// Sending in normal mode
		HAL_Delay(500);

    /* USER CODE BEGIN 3 */
	  }

	  if (HAL_GPIO_ReadPin(GPIOA, GPIO_PIN_9) != 0){

    /* USER CODE END WHILE */
		uint8_t Test[] = "Hit 5!!!\r\n"; //Data to send
		HAL_UART_Transmit(&hlpuart1,Test,sizeof(Test),10);// Sending in normal mode
		HAL_Delay(500);

    /* USER CODE BEGIN 3 */
	  }

	  if (HAL_GPIO_ReadPin(GPIOA, GPIO_PIN_10) != 0){

    /* USER CODE END WHILE */
		uint8_t Test[] = "Hit 7!!!\r\n"; //Data to send
		HAL_UART_Transmit(&hlpuart1,Test,sizeof(Test),10);// Sending in normal mode
		HAL_Delay(500);

    /* USER CODE BEGIN 3 */
	  }


  }





	  		//HAL_GPIO_TogglePin(GPIOB, GPIO_PIN_1);
  /* USER CODE END 3 */
}

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


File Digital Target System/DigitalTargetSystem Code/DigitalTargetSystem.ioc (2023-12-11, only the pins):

Mcu.UserName=STM32L031K6Tx
PA0-CK_IN.Signal=GPIO_Input
PA1.Signal=GPIO_Input
PA10.Signal=GPIO_Input
PA13.Signal=SYS_SWDIO
PA14.Signal=SYS_SWCLK
PA2.Signal=LPUART1_TX
PA3.Signal=LPUART1_RX
PA4.Signal=GPIO_Input
PA5.Signal=GPIO_Input
PA6.Signal=GPIO_Input
PA7.Signal=GPIO_Input
PA8.Signal=GPIO_Input
PA9.Signal=GPIO_Input

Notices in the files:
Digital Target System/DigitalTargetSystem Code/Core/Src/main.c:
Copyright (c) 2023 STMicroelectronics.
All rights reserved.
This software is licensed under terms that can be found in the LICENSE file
